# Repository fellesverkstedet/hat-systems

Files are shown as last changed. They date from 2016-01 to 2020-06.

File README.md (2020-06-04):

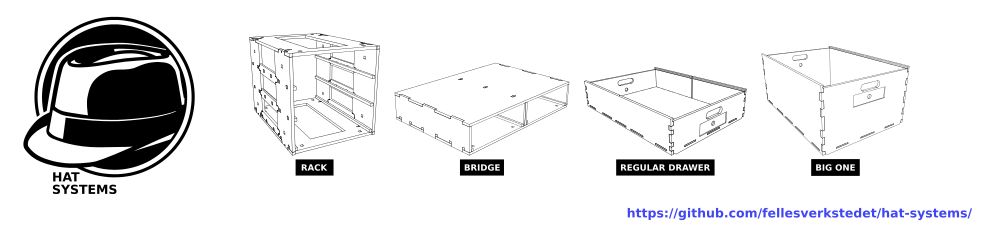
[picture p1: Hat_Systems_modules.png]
Modules overview


# Hat Systems
Hat Systems is a general purpose storage system for workshop storage of tools and inventory.

Designed with these basic principles in mind; modular, low-cost, heavy-duty/durable and spacious. The module sizes is designed to fit onto [EUR-palett](https://en.wikipedia.org/wiki/EUR-pallet), with a footprint size of 120x80 centimeter. This allows them to be moved around easily in an production or workshop environment, or even transported between locations.

Originally developed as for use in-house at [Fellesverkstedet](http://fellesverkstedet.no), now also in use at [Bitraf](http://bitraf.no), and open for reproduction across the world.

## License

Distributed under Creative Commons Attribution 4.0 International. [CC-BY 4.0](http://creativecommons.org/licenses/by/4.0/).

## Contributors
Conceptualized for Fellesverkstedet by [Hans Christian Skovholt](http://www.skovholt.net/) and Graham A. Hayward.

Modules have been produced by Jonas Sætervik, [Siemen Cuypupeiers](http://www.siemencuypers.com) and Anthony Poldervaart. And by Thomas Winther at Bitraf.

Have you made a Hat Systems module? Or have designed additional modules? [Let us know!](https://github.com/fellesverkstedet/hat-systems/issues/new).

## Example configurations

### Storage shelves

Per palett: `2x2 Rack`, with  `3x Drawer Regular` in most of the racks.

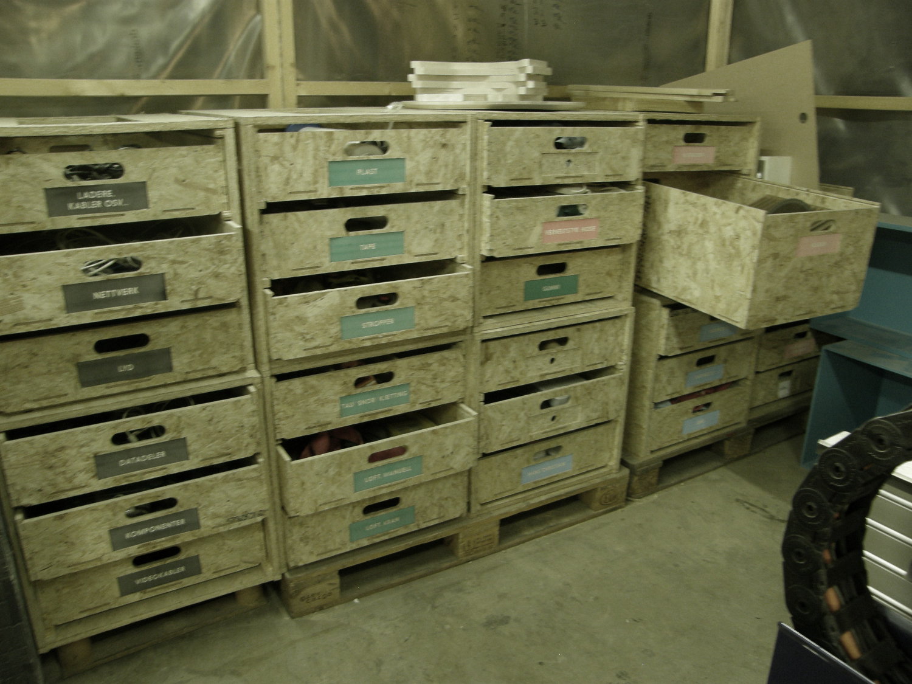
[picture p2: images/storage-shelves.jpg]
Storage shelves at Fellesverkstedet


### Laser material storage

`1x Material Storage` with `1x Bridge` on top.

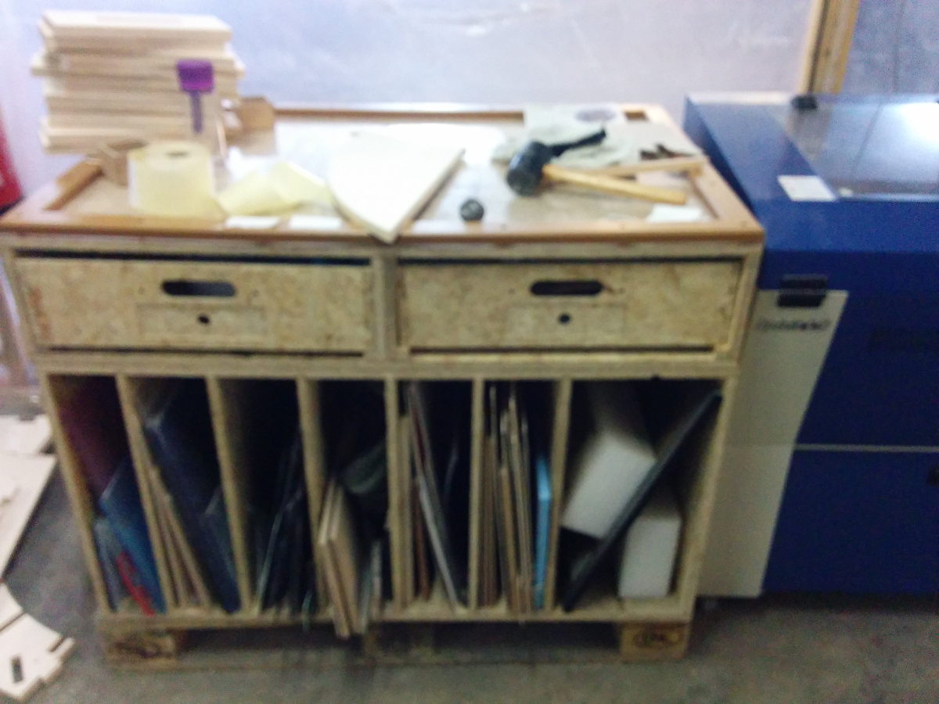
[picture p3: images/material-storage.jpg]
Material Storage for laser


## Roller table with drawers

`1x Rack` with `3x Drawer Regular`, a benchplate on top and wheels mounted underneath.
Very useful for moving large cutsheets and finished parts around workshop, to and from CNC router.

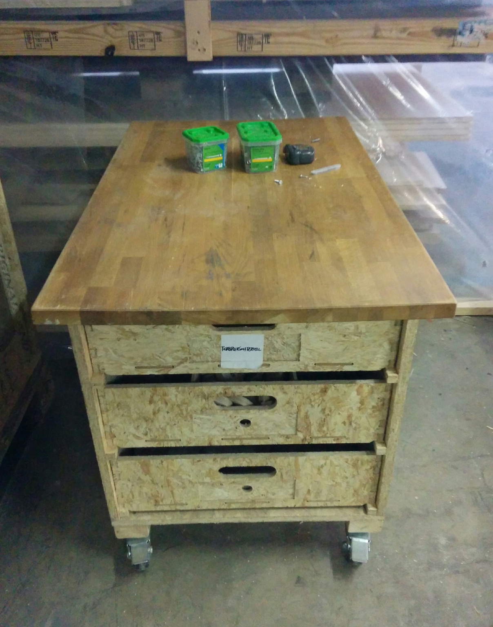
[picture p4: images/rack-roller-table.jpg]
Roller table with drawers


## Collaboration table

`2x Rack` with a tabletop made out of one old sacrificial layer from CNC and one white-painted sheet (120x240cm).
Comfortable to stand and work around, or one can sit on bar-style stools.

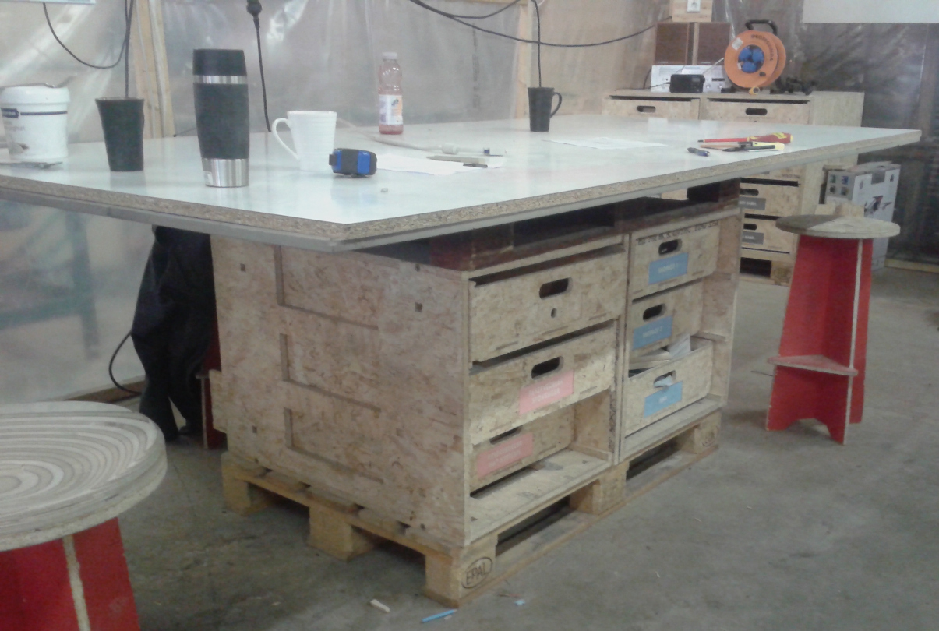
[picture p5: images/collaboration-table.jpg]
Big collaboration table


## Machine tools workbench

The machines on top of the work surface are each attached to a plate with chamfered edges.
An opposing chamfered edge in back, and  hinged profile in front locks the plates in place.
This allows some flexibility in moving the machines around.

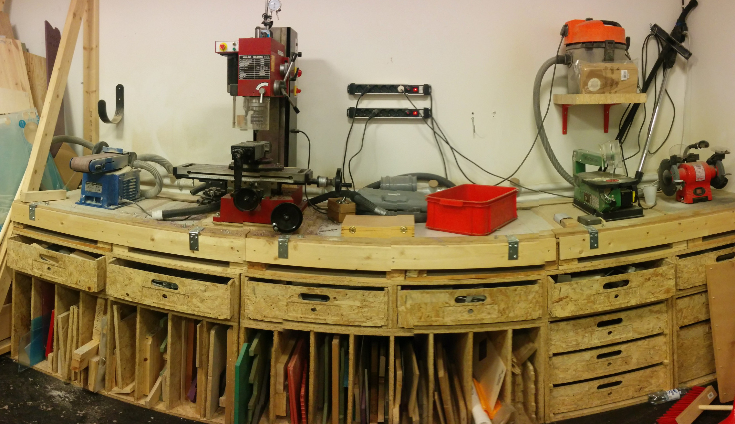
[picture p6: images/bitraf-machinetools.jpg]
Machine tools workbench

Picture from Bitraf makerspace.

## Prerequisites for making
You will need accesss to a large-scale CNC mill/router, capable of handling cutsheets of at least 60x80 cm (120x80 for current bridge design),
and cutting 18 mm [OSB](https://en.wikipedia.org/wiki/Oriented_strand_board).
Examples include the Shopbot PRS, or an extended Shapeoko/XCarve.

If you don't have access to such a machine, check out your local [FabLab](https://www.fablabs.io/map), makerspace or [hackerspace](https://wiki.hackerspaces.org/List_of_Hacker_Spaces)! Or find someone to manufacture it for you locally using [Fabhub.io directory](https://www.fabhub.io/directory).

Ready-to-use cutsheet geometry is included, but you will need to set up the toolpaths yourself using the CAM software for your machine.

## Modules

[Sketchup project source](./Hat_Systems_assembled.skp), for modifying or creating new modules.

### Rack

The base module, which drawers fit into.

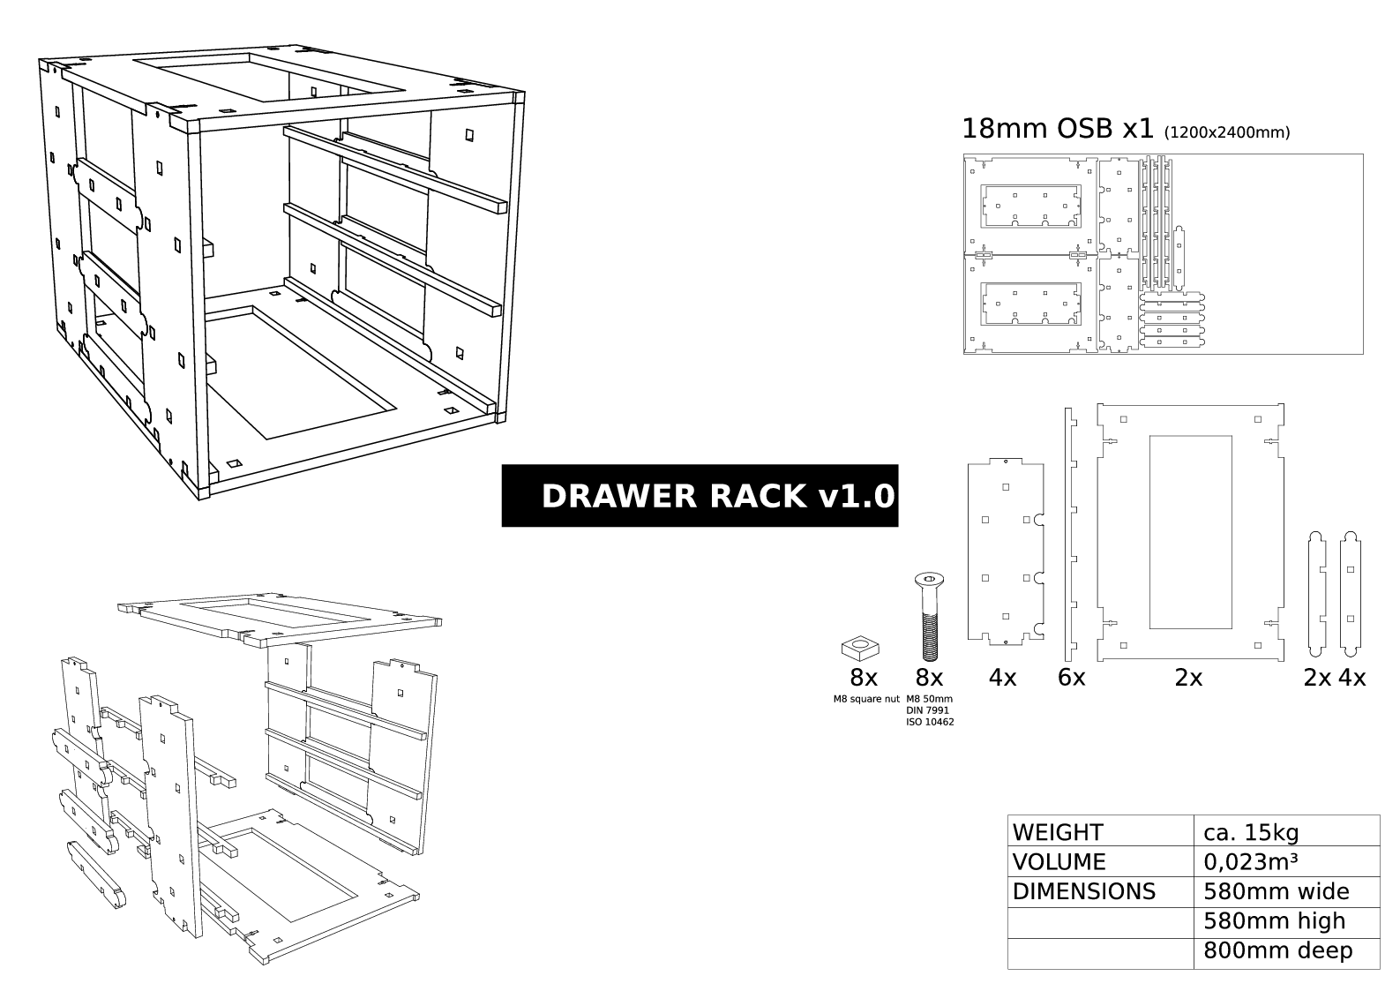
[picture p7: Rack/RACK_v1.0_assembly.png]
Rack assembly drawing


Made of 18mm OSB.

Is put together with 8 countersunk socket head M8 x 50mm bolts and square nuts M8 x 13 x 5MM (DIN 7991/ISO 10462).
The countersunk bolts facilitates placing two units side by side on a pallett.

The rack is assembled with bolts in order to make it possible to dissasemble for transport. But could theoretically be glued or screwed together as well.

[.DXF original geometry](./Rack/RACK_full_sheet_v1.0_no_dogbones_no_hdd.dxf) | 
[Cutsheet .DXF (includes dogboones & holddown, for <=6mm tool)](./Rack/RACK_full_sheet_v1.0_6mm_dogbones.dxf) | 
[.STL 3d-model](./Rack.stl)

### Drawer Regular

Regular drawer that will fit most stuff.

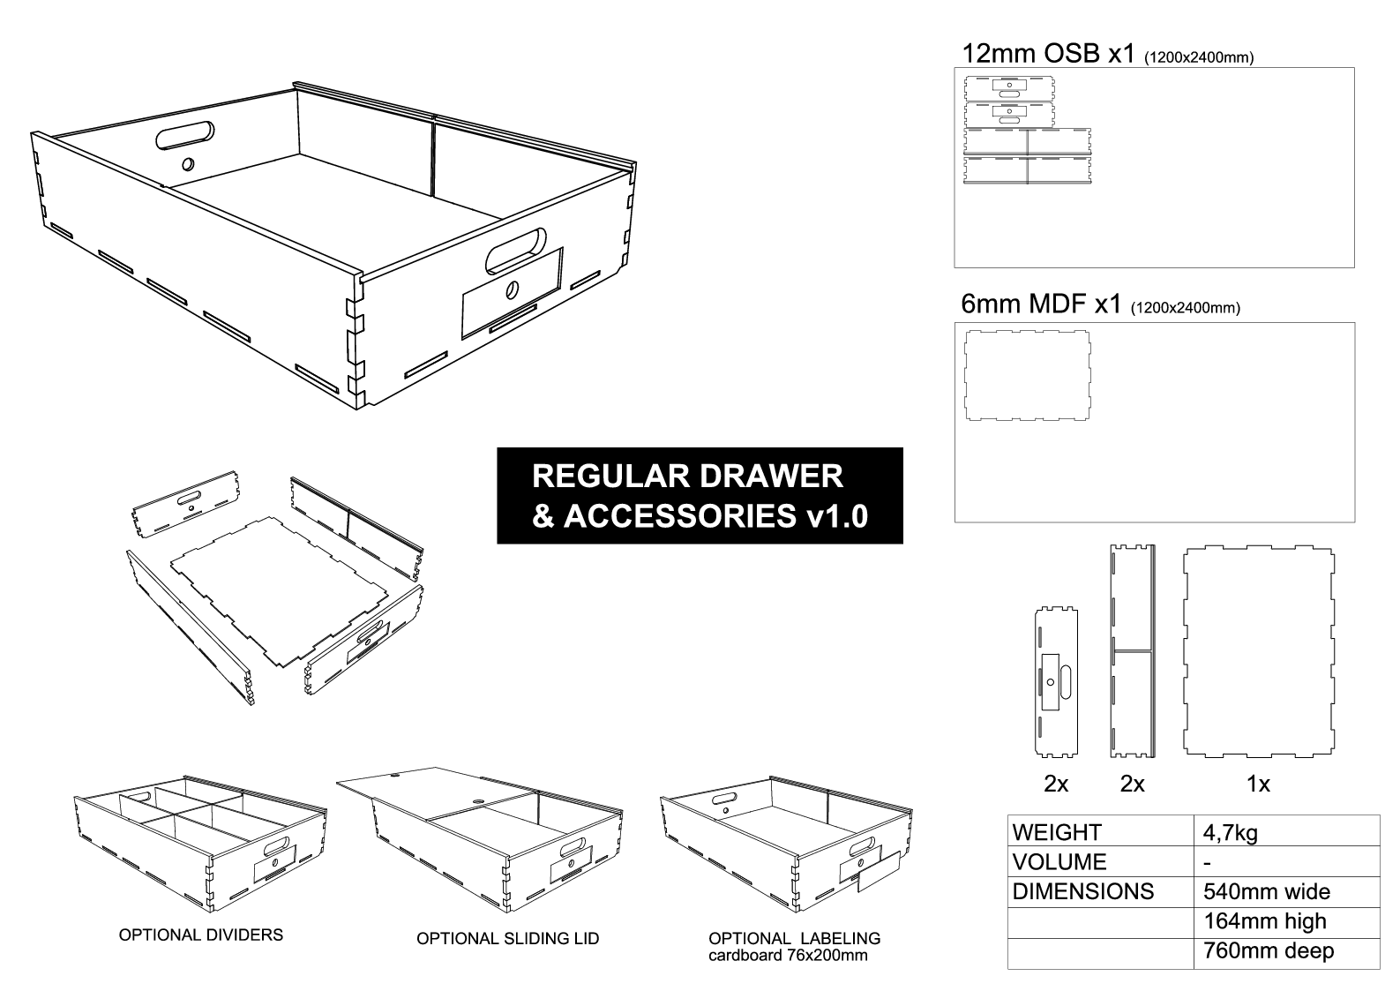
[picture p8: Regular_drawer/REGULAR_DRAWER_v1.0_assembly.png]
Drawer Regular assembly drawing


Made of 12mm OSB, as well as 6mm MDF for drawer bottoms.

[.DXF original geometry](./Regular_drawer/DRAWERS_REGULAR_full_sheet_v1.0_no_dogbones_no_hdd.dxf) | 
[Cutsheet .DXF (includes dogboones & holddown, for <=6mm tool)](./Regular_drawer/DRAWERS_REGULAR_full_sheet_v1.0_6mm_dogbones.dxf) | 
[.STL 3d-model](./Drawer_regular.stl)

You will also need one drawer bottom.

[.DXF original geometry](./Drawer_bottom/DRAWER_BOTTOM_full_sheet_v1.0_no_dogbones_no_hdd.dxf) | 
[Cutsheet .DXF (includes dogboones & holddown, for <=6mm tool)](./Drawer_bottom/DRAWER_BOTTOM_full_sheet_v1.0_6mm_dogbones.dxf) | 

### Drawer BigOne

Supersized drawer, takes the place of two regular drawers in height. Otherwise identical to Drawer Regular.

[.DXF original geometry](./Big_One_drawer/BIG_ONE_Drawer_no_dogbones.dxf) | 
[Cutsheet .DXF (includes dogboones & holddown, for <=6mm tool)](./Big_One_drawer/BIG_ONE_Drawer_6mm_dogbones.dxf) | 
[.STL 3d-model](./Drawer_big_one.stl)

You will also need one drawer bottom, see above!

### Bridge

Forms a solid surface on top of two racks, as well as housing for two regular drawers.
Useful to create a working sturface, with height comfortable for standing work.

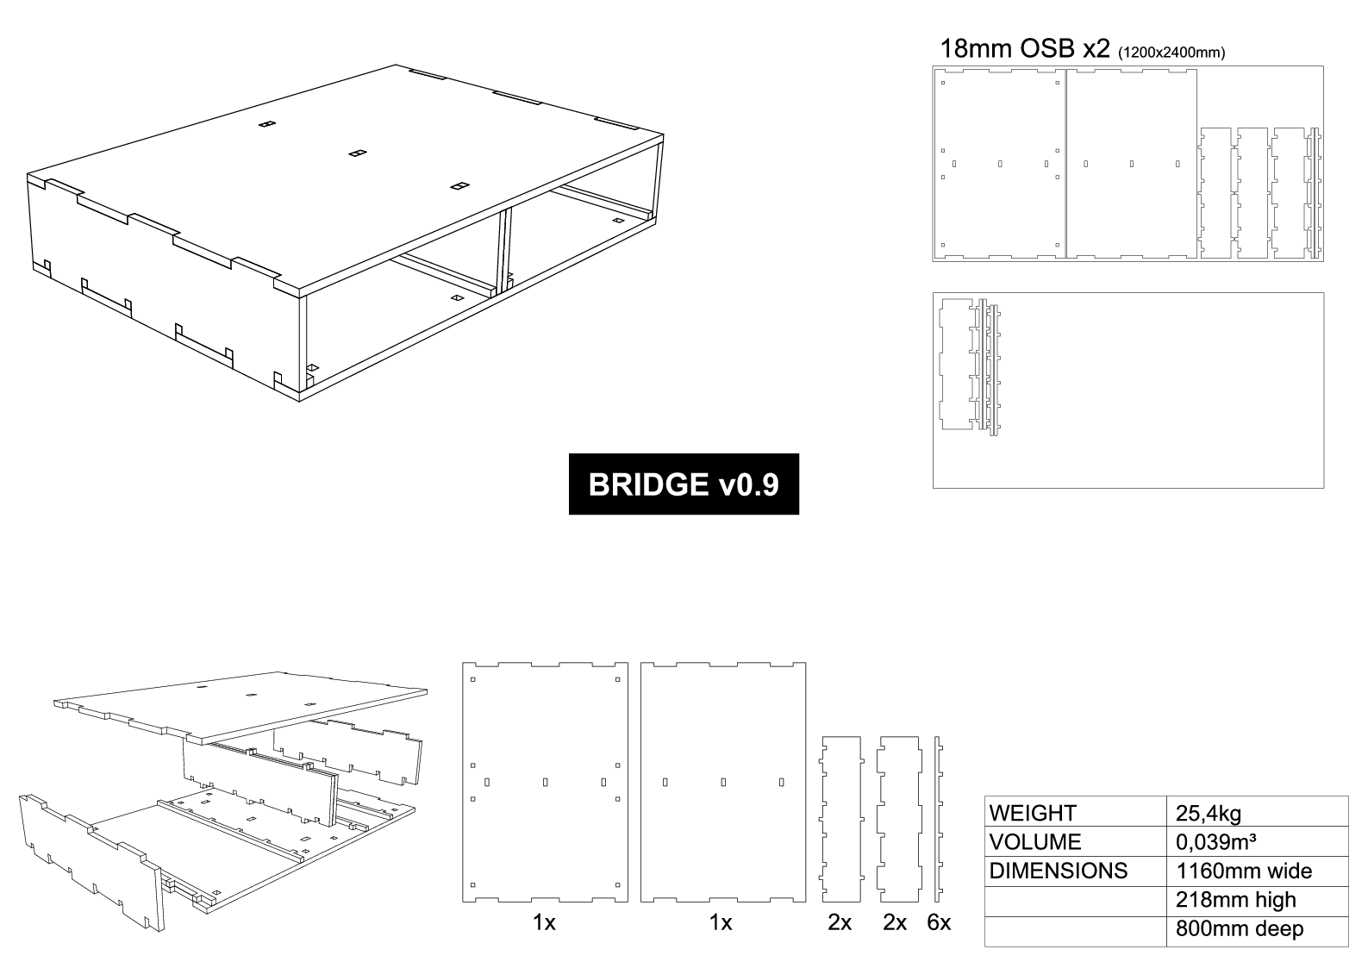
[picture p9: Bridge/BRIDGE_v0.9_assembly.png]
Bridge assembly drawing


Original geometry [.DXF 1](./Big_One_drawer/Bridge/BRIDGE_v0.9_no_dogbones_1of2.dxf) [.DXF 2](./Big_One_drawer/Bridge/BRIDGE_v0.9_no_dogbones_2of2.dxf) | 

## Material Storage

Full-width module for storing materials vertically.

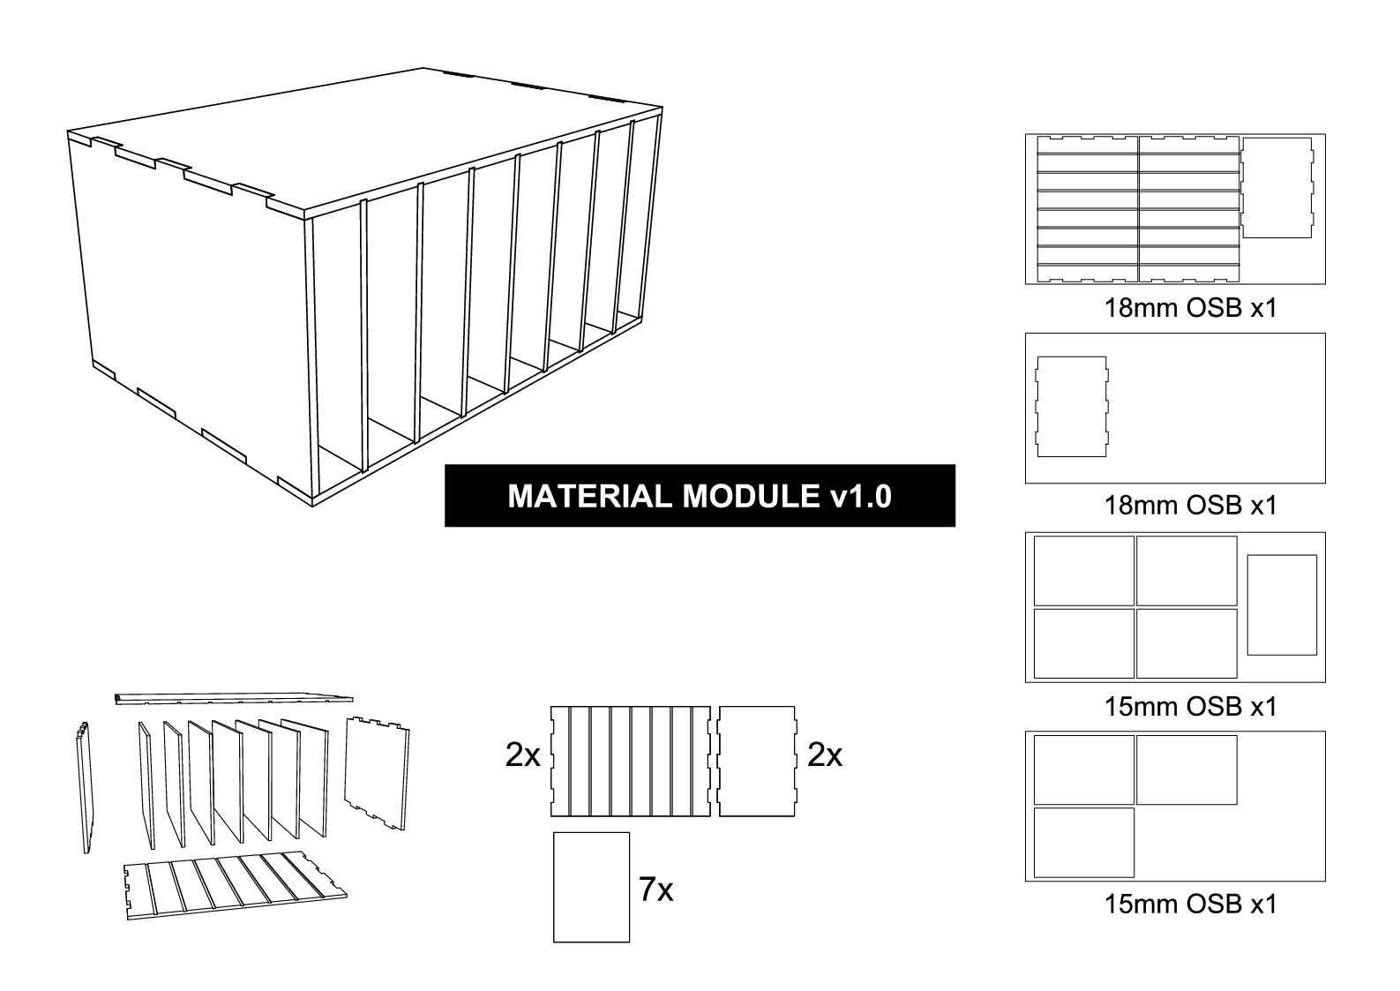
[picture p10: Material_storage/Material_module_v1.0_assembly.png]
Material storage assembly drawing


**Work-in-progress!** Files should be scrutinized before any attempt to produce.

[Sketchup project](./Material_storage/Material_storage.skp) | 
[.DXF export](./Material_storage/Material_storage.dxf) | 
[.STL 3d-model](./Material_storage/Material_storage.stl)

## Trash cans

**Work-in-progress!** Files currently missing.

Trash can rack, including 3x trash cans.

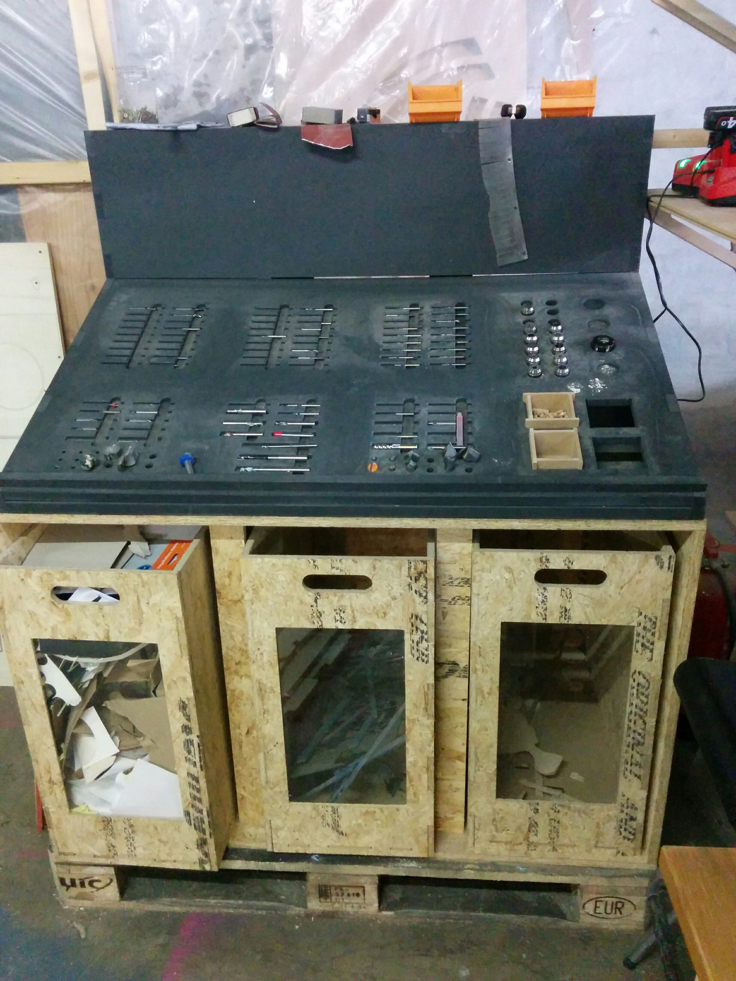
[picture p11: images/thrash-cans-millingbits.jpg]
Trash cans module


The ER20 collet and milling bit holder on top is also to-be-released.

### Design iterations in the wild
* A [bedbunk drawer](https://github.com/apetrynet/bunk_drawers) variation by apetrynet, designed in Freecad

## TODO

* Add picture of Bitraf island module, and design files
* Material Storage: Finish/verify files, mark complete.
* Rack: Remove mostly-unused bolt holes in sides. They stay still by their own weight.
* Add a template .SVG file for drawer label (for ease of making on laser/printer)
* Trash cans: Publish files, create assembly drawing
* Milling bit holder: Publish in separate project, link here

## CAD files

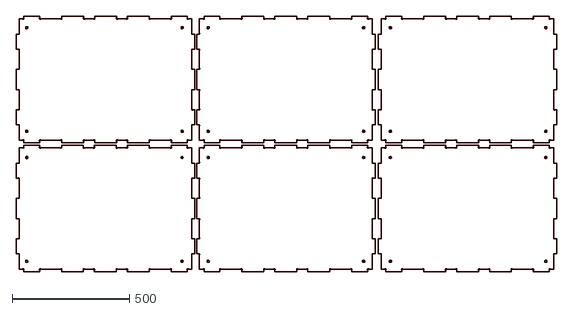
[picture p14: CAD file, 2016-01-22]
Drawer_bottom/DRAWER_BOTTOM_full_sheet_v1.0_6mm_dogbones.dxf
2301.5 x 1089.0

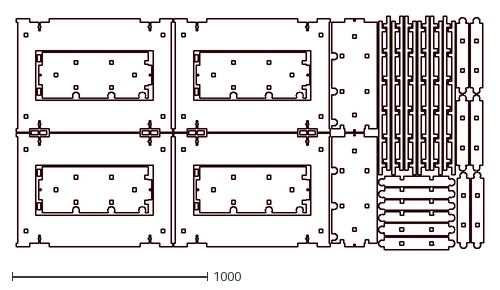
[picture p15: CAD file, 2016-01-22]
Rack/RACK_full_sheet_v1.0_no_dogbones_no_hdd.dxf
2390.7 x 1194.8

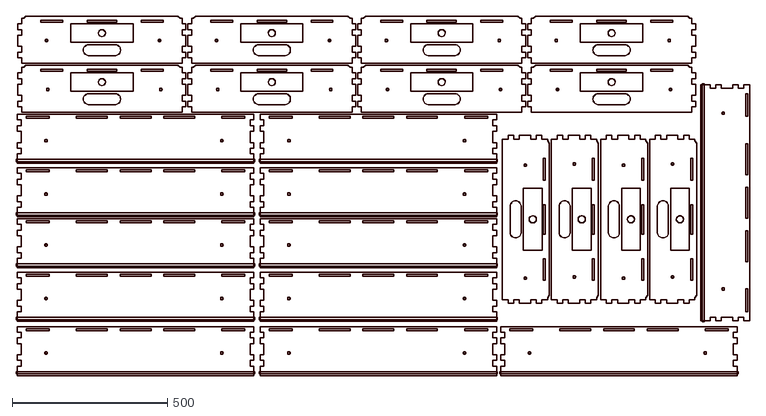
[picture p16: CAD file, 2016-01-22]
Regular_drawer/DRAWERS_REGULAR_full_sheet_v1.0_no_dogbones.dxf
2357.3 x 1155.5

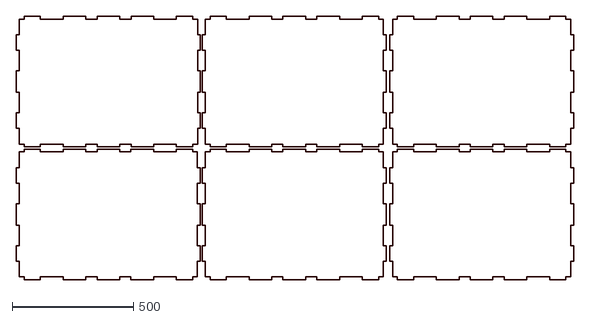
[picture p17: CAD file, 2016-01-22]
Drawer_bottom/DRAWER_BOTTOM_full_sheet_v1.0_no_dogbones_no_hdd.dxf
2301.5 x 1089.0

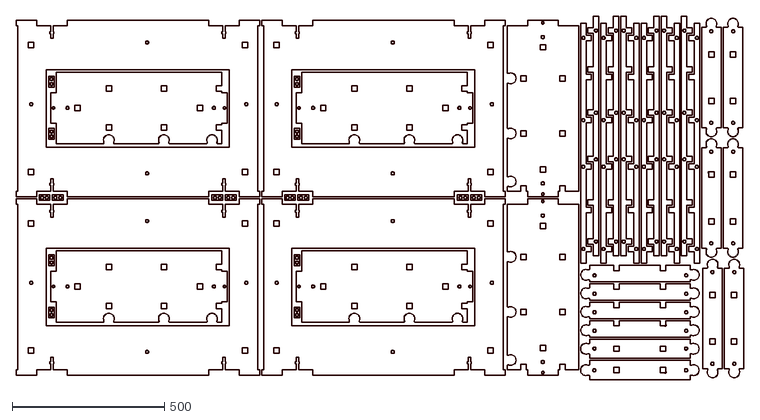
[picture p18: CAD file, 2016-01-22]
Rack/RACK_full_sheet_v1.0_no_dogbones.dxf
2390.7 x 1194.8

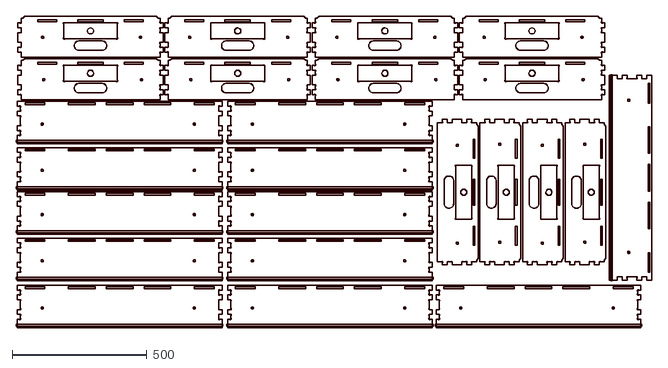
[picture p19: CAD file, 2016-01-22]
Regular_drawer/DRAWERS_REGULAR_full_sheet_v1.0_6mm_dogbones.dxf
2357.3 x 1155.5

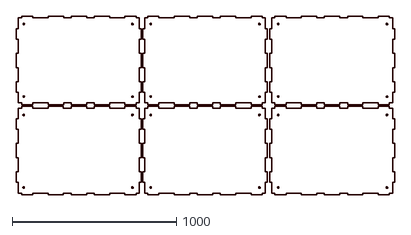
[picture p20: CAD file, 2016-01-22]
Drawer_bottom/DRAWER_BOTTOM_full_sheet_v1.0_no_dogbones.dxf
2301.5 x 1089.0

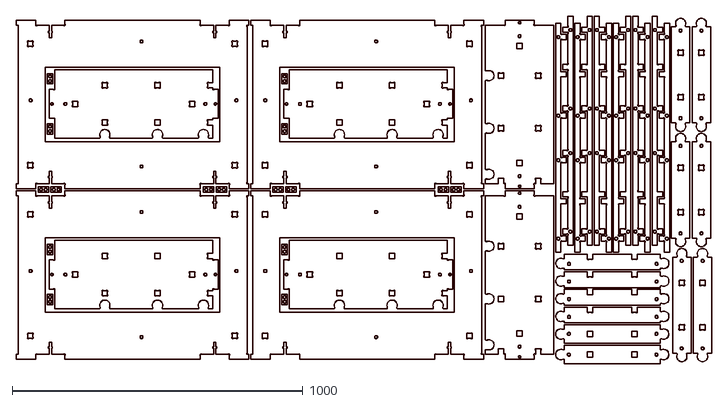
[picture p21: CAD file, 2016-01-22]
Rack/RACK_full_sheet_v1.0_6mm_dogbones.dxf
2390.7 x 1194.8

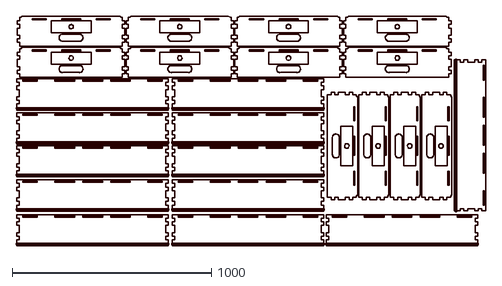
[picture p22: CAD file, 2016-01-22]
Regular_drawer/DRAWERS_REGULAR_full_sheet_v1.0_no_dogbones_no_hdd.dxf
2357.3 x 1155.5

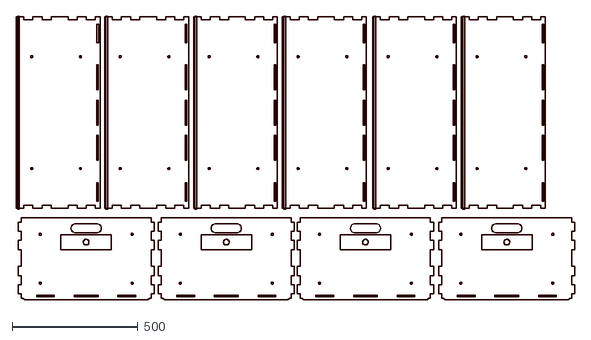
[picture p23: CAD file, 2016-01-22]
Big_One_drawer/BIG_ONE_Drawer_no_dogbones.dxf
2217.9 x 1126.4

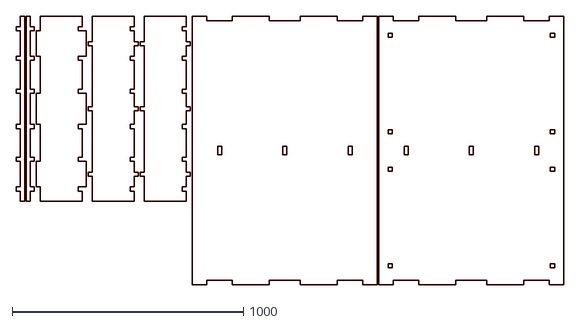
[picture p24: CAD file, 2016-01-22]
Bridge/BRIDGE_v0.9_no_dogbones_1of2.dxf
2369.5 x 1160.0

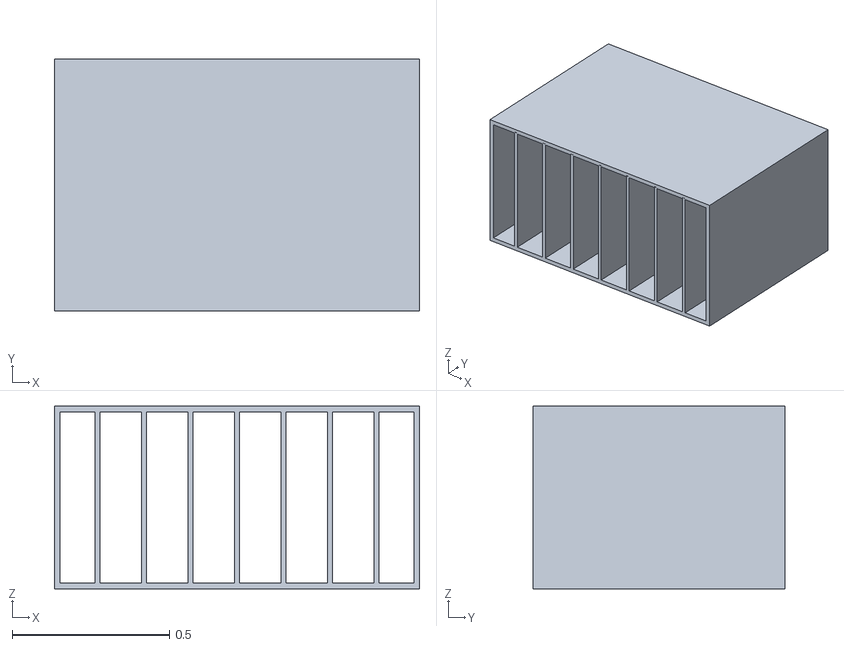
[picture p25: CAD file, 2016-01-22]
Material_storage/Material_storage.stl
1.16 x 0.8 x 0.58

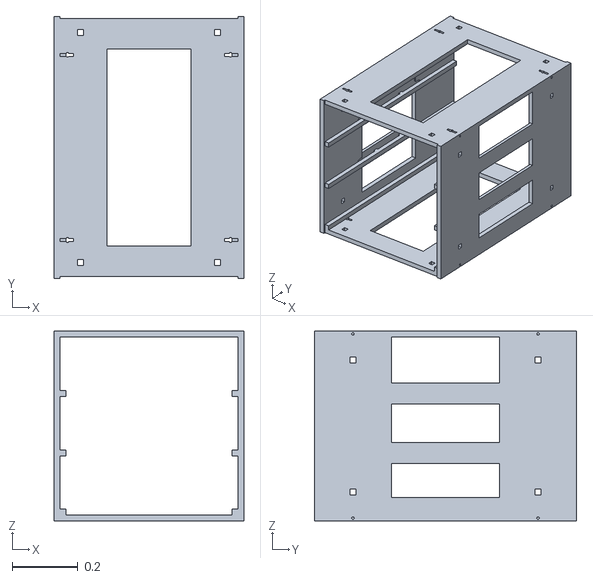
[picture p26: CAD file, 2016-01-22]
Rack.stl
0.58 x 0.8 x 0.58

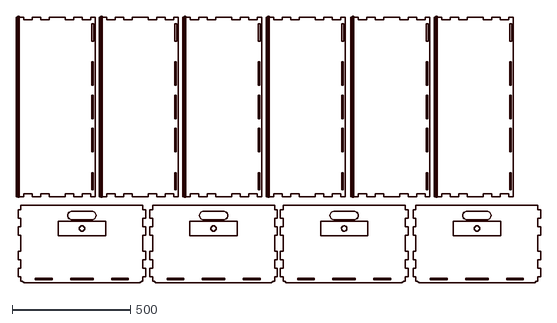
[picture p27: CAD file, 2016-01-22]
Big_One_drawer/BIG_ONE_Drawer_no_dogbones_no_hdd.dxf
2217.9 x 1126.4

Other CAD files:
Bridge/BRIDGE_v0.9_no_dogbones_sheet_2of2.dxf
Drawer_big_one.stl
Big_One_drawer/BIG_ONE_Drawer_6mm_dogbones.dxf
Drawer_regular.stl
Hat_Systems_assembled.skp
Material_storage/Material_storage.dxf
Material_storage/Material_storage.skp

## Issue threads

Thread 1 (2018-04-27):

Avoiding loose pieces

Jaknil, 2018-04-27:
If the parts for the rack are CAMed with only hold-down and profile and cut with an up-cut bit, then there is a large chance that there will be loose pieces popping out of the cut sheet potentially jamming the machine or worse. I suggest that some hold down holes are added to the long sides and that the small pieces are removed with a pocket operation, some profiles need to be added for this.

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

Note: This happened, the X-axis stalled, causing the bit to hit a screw, get damaged and go wild in the sheet leaving burn marks before the machine was stopped. We switched to a compression bit which left the floating pieces in the sheet.

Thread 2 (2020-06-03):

Hat-System variation, paying my dues :)

apetrynet, 2020-06-03:
Hey!

I just wanted to let you know that I'm creating a [variation](https://github.com/apetrynet/bunk_drawers) of the Hat-System for storage under my summer cabin bunk bed.

Thanks for this awesome design!

JensDyvik, 2020-06-04:
Super awesome to see Daniel. Thank your for sharing the link! And great to see you are working with freecad. I have grown very fund of working with freecad lately. Especially using the a spreadsheet with aliases as a parametric design interface/driver

Closed 2020-06-04.

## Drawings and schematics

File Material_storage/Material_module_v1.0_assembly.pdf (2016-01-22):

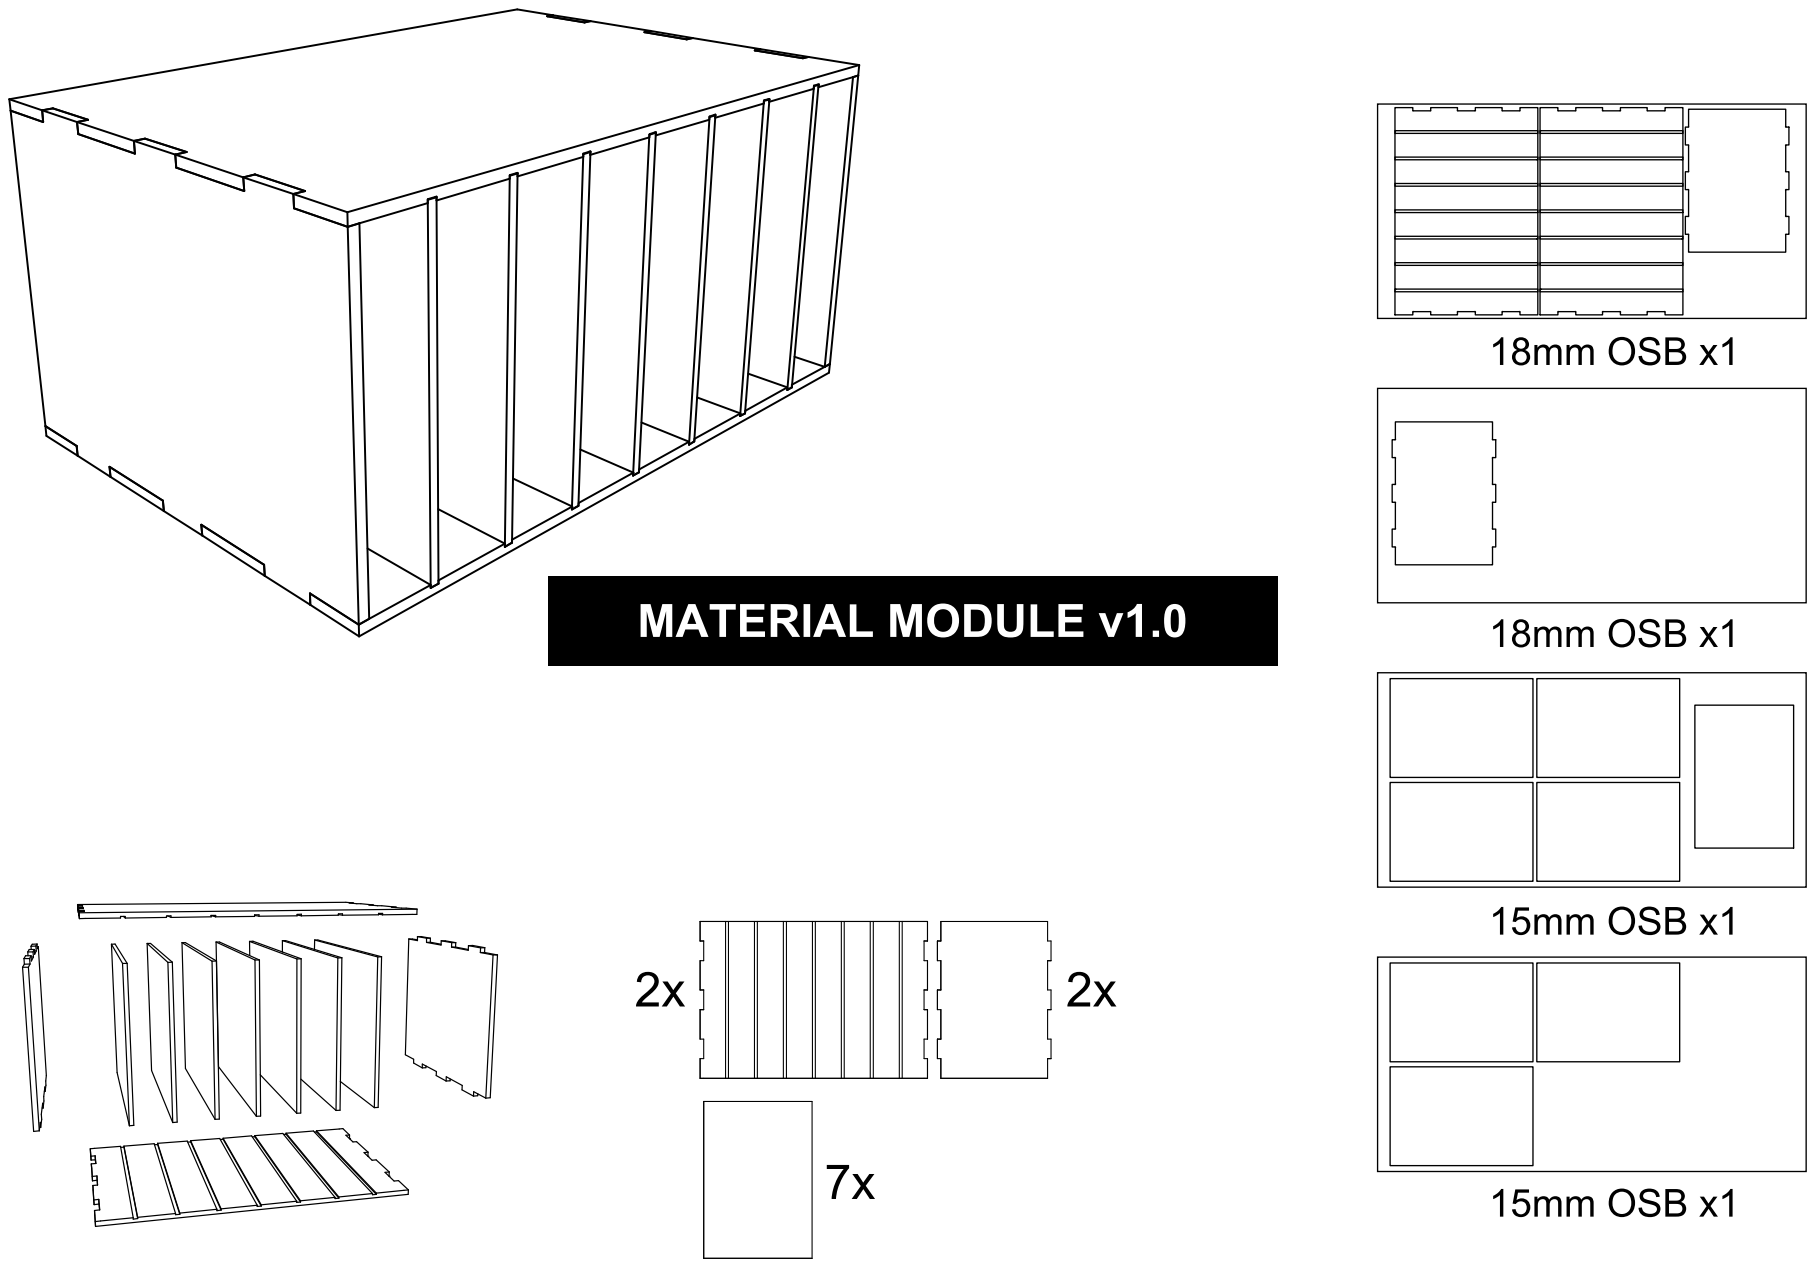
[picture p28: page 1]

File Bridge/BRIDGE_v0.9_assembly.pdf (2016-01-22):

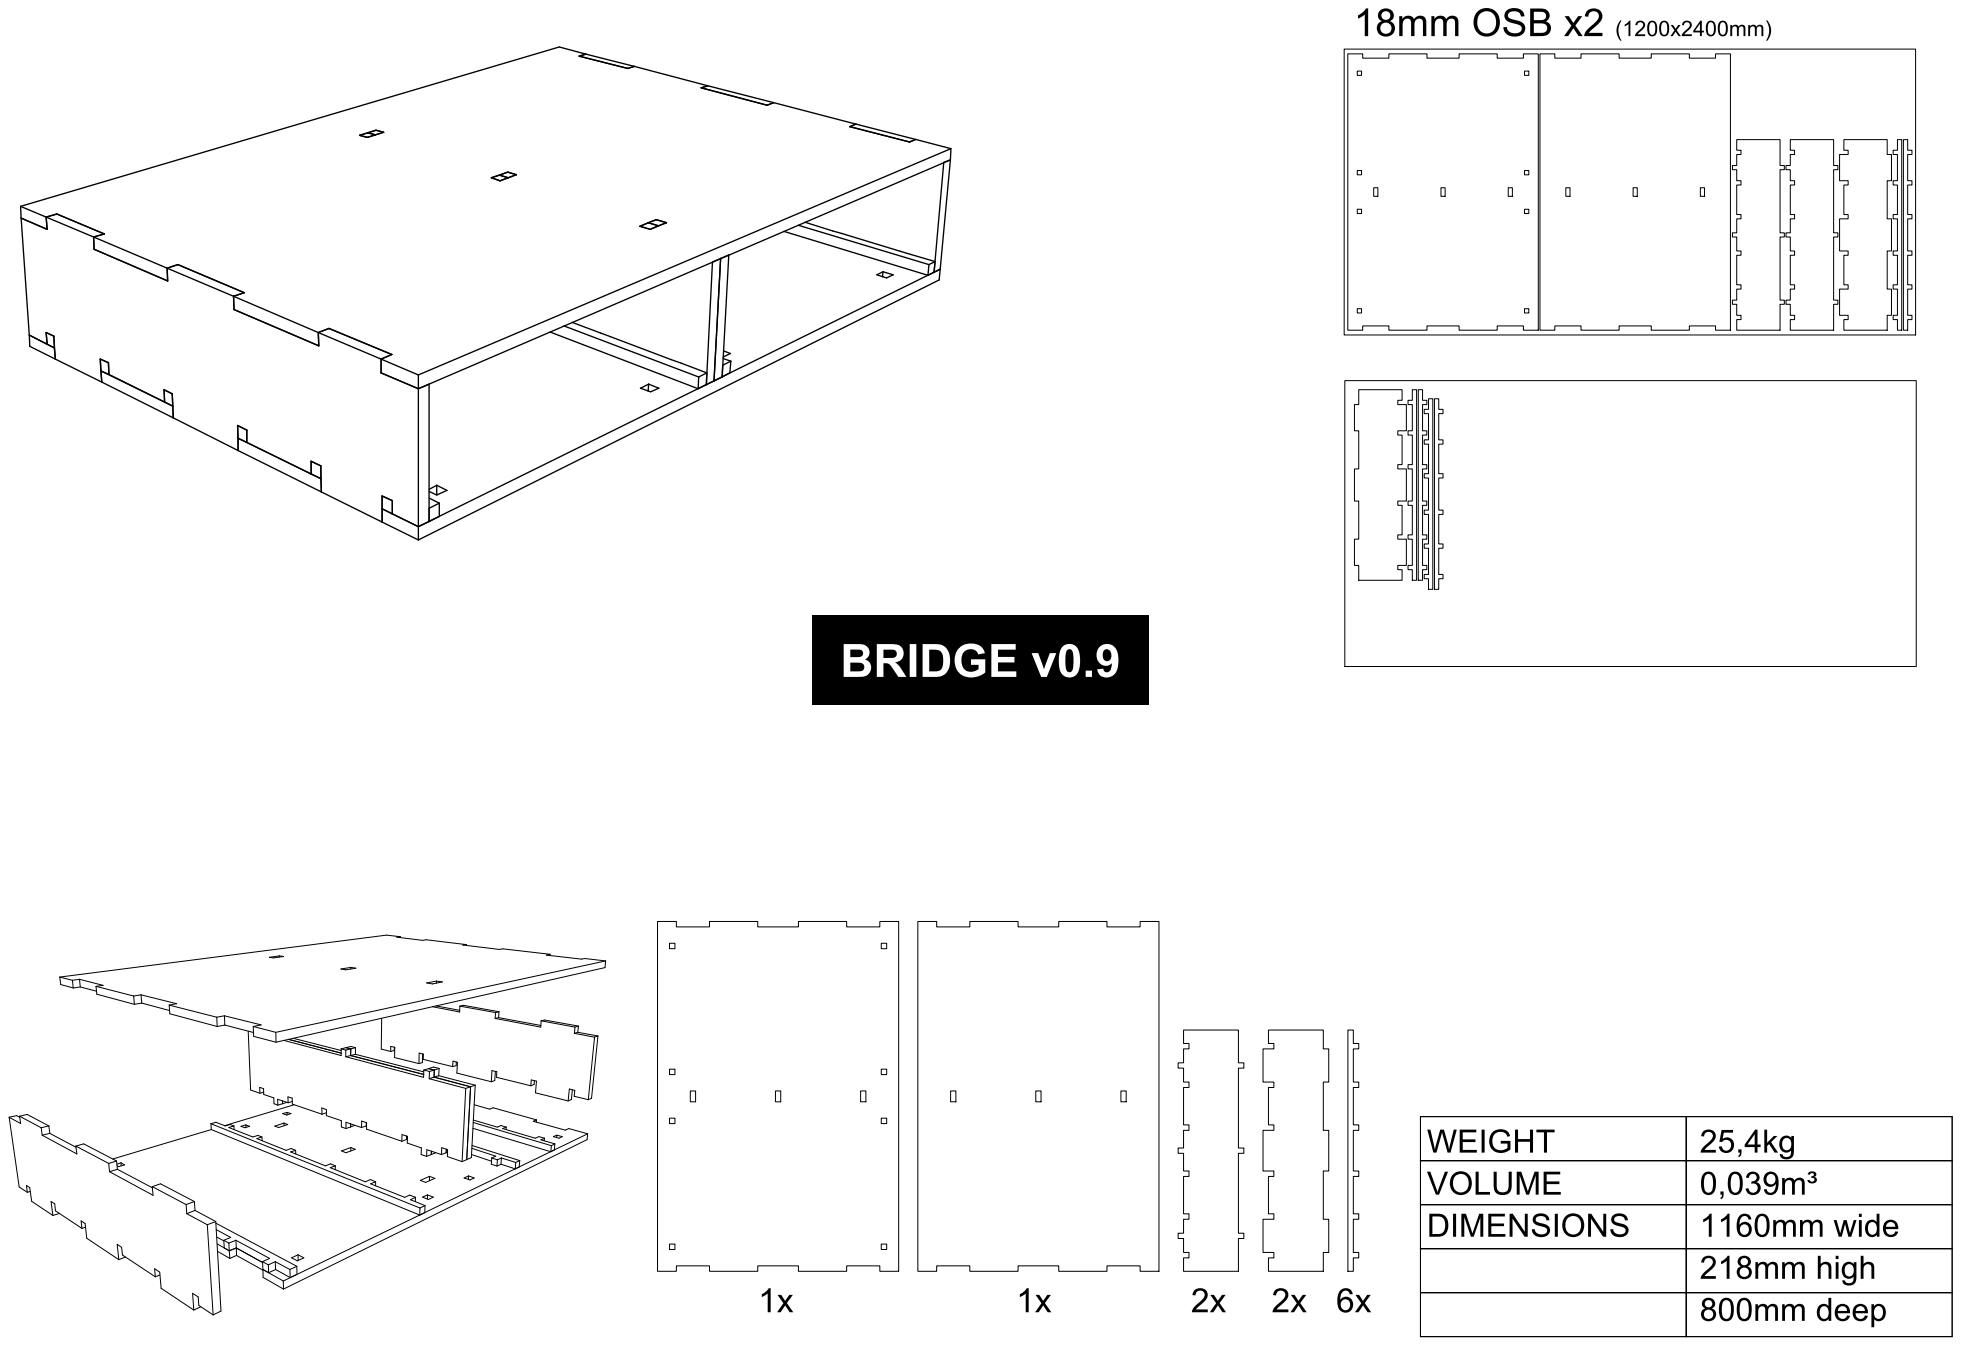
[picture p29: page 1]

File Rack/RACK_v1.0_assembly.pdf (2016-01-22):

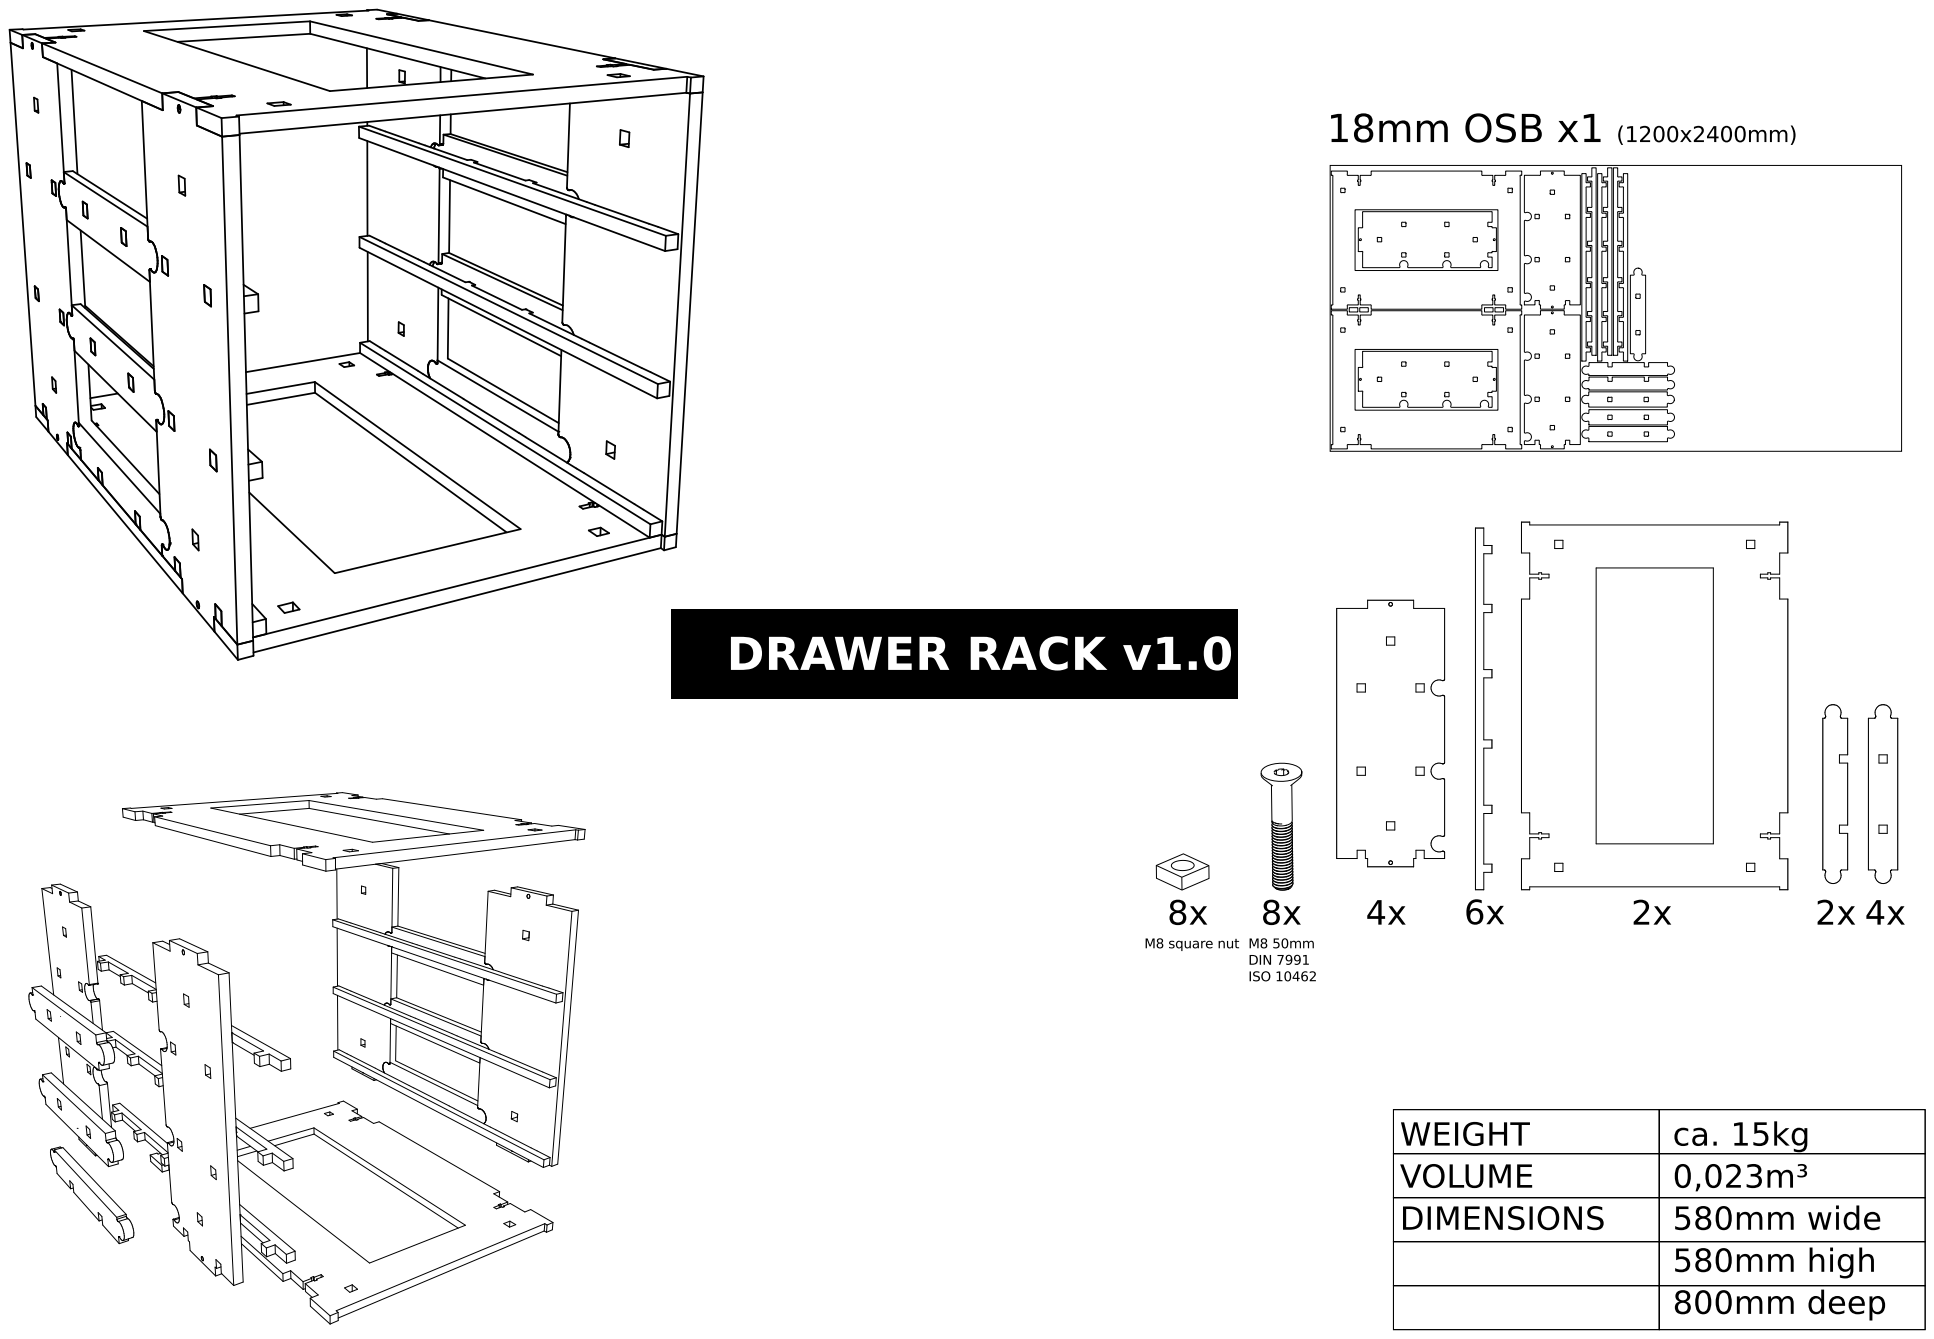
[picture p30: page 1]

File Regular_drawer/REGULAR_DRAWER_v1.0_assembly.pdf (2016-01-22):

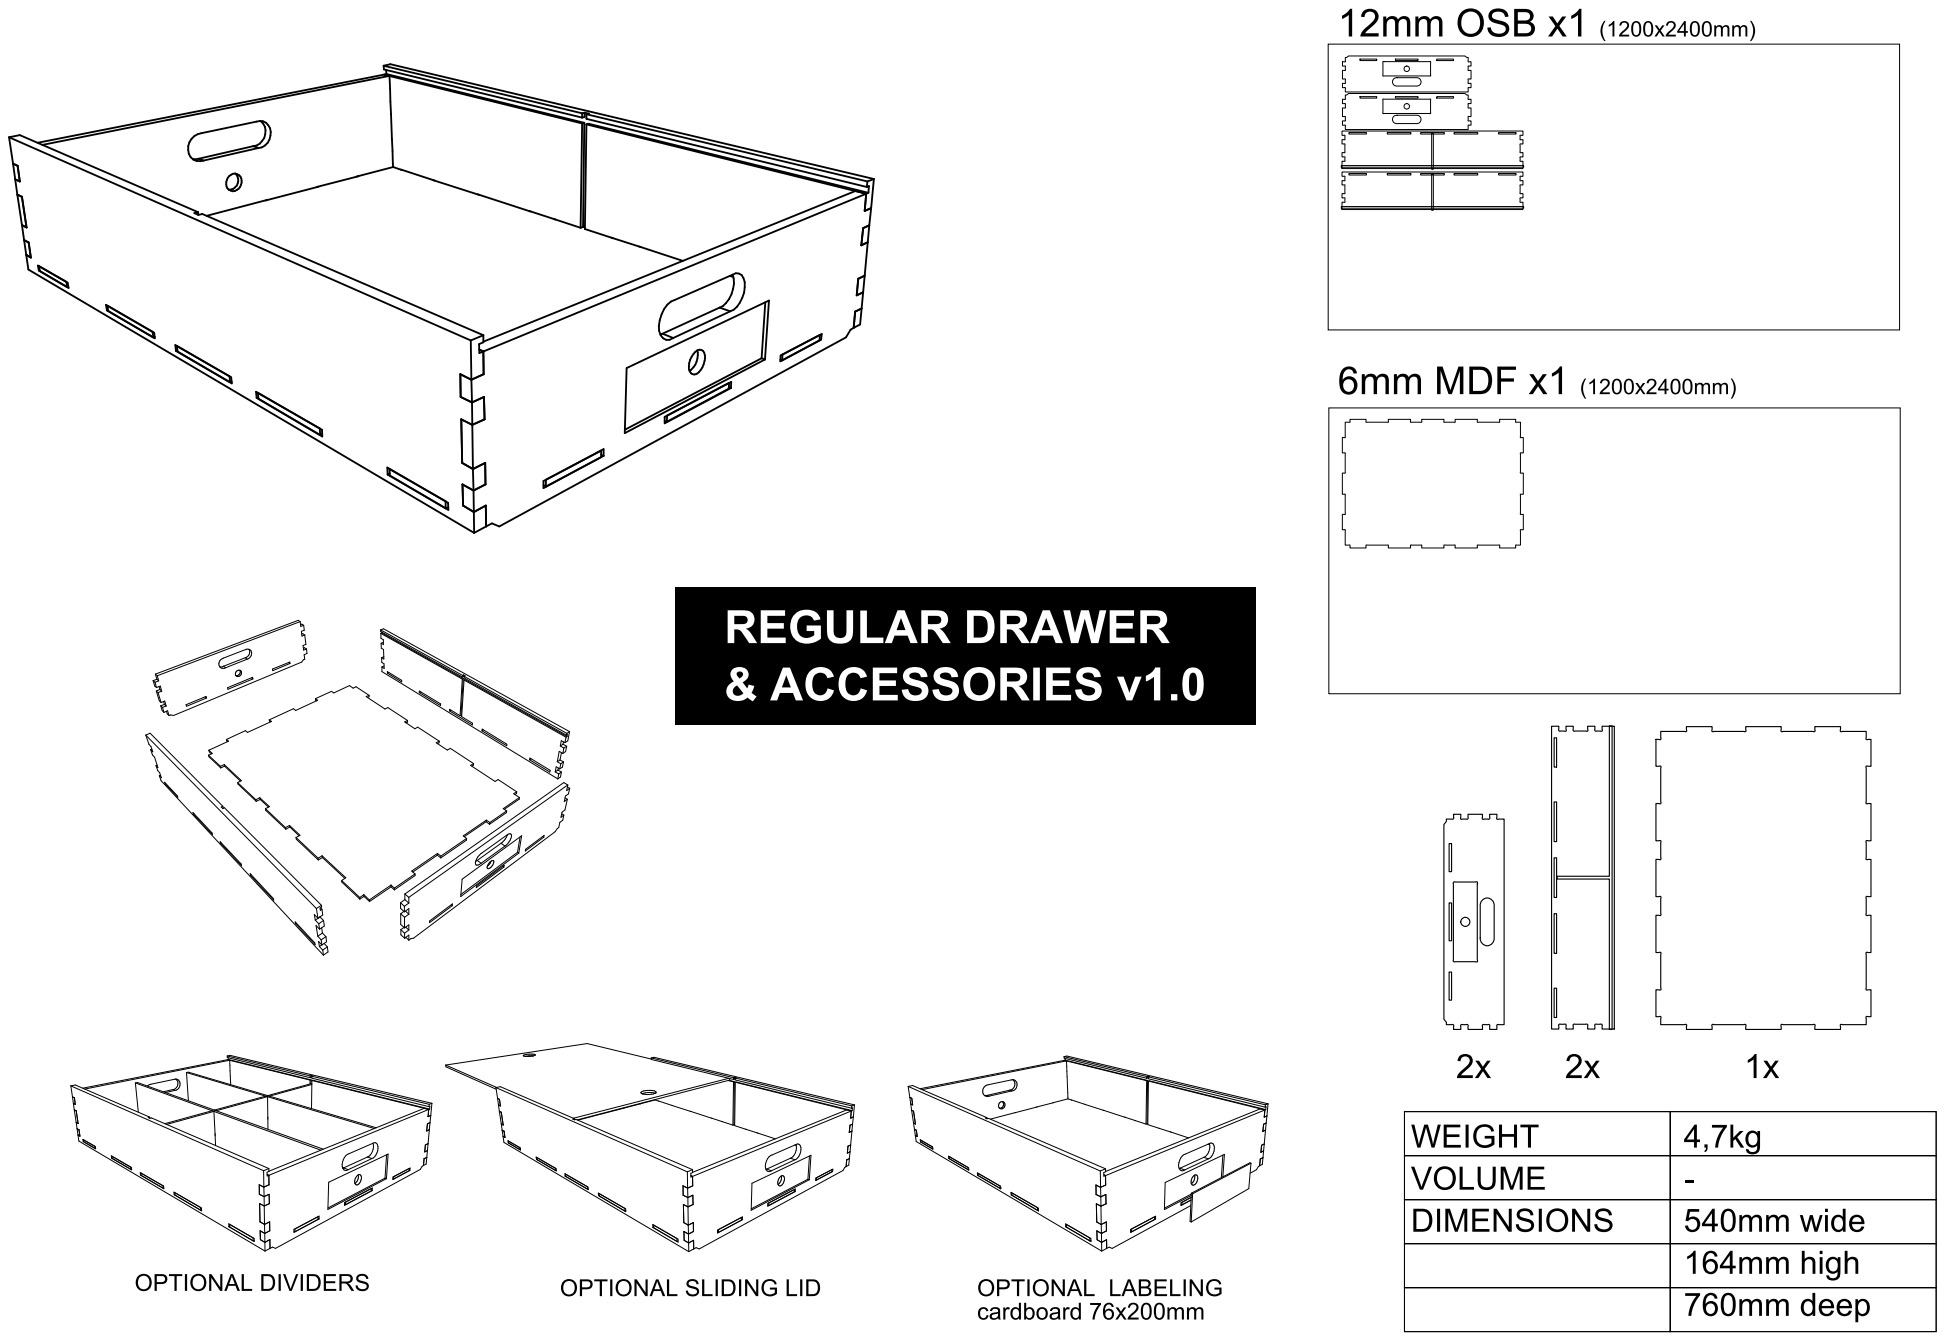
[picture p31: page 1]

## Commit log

2016-01-22 Delete BIG_ONE_Drawer_6mm_dogbones.dxf
    cleanup
    [BIG_ONE_Drawer_6mm_dogbones.dxf]
2016-01-22 Delete BIG_ONE_Drawer_no_dogbones.dxf
    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
    [BIG_ONE_Drawer_no_dogbones.dxf]
2016-01-22 Delete BIG_ONE_Drawer_no_dogbones_no_hdd.dxf
    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
    [BIG_ONE_Drawer_no_dogbones_no_hdd.dxf]
2016-01-22 Delete BRIDGE_v0.9_no_dogbones_1of2.dxf
    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
    [BRIDGE_v0.9_no_dogbones_1of2.dxf]
2016-01-22 Delete BRIDGE_v0.9_no_dogbones_sheet_2of2.dxf
    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
    [BRIDGE_v0.9_no_dogbones_sheet_2of2.dxf]
2016-01-22 Delete DRAWERS_REGULAR_full_sheet_v1.0_6mm_dogbones.dxf
    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
    [DRAWERS_REGULAR_full_sheet_v1.0_6mm_dogbones.dxf]
2016-01-22 Delete DRAWERS_REGULAR_full_sheet_v1.0_no_dogbones.dxf
    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
    [DRAWERS_REGULAR_full_sheet_v1.0_no_dogbones.dxf]
2016-01-22 Delete DRAWERS_REGULAR_full_sheet_v1.0_no_dogbones_no_hdd.dxf
    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
    [DRAWERS_REGULAR_full_sheet_v1.0_no_dogbones_no_hdd.dxf]
2016-01-22 Move assembly drawing into module directories
2016-01-22 Remove duplicate files, now inside Rack/ and Drawer_bottom/
    [DRAWER_BOTTOM_full_sheet_v1.0_6mm_dogbones.dxf, DRAWER_BOTTOM_full_sheet_v1.0_no_dogbones.dxf, DRAWER_BOTTOM_full_sheet_v1.0_no_dogbones_no_hdd.dxf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]
2016-01-22 Add rendered PNGs of assembly PDFs
    Generated using
    ./scripts/assembly-pngs.sh
2016-01-22 README: Add assembly drawing images
2016-01-22 Rename assembly images to .png
    Looks like Github Pages does not show .pdf.png as images
2016-01-22 README: Mention that bridge needs 120 cm CNC
2016-01-22 material storage module
    [Material_storage.dxf, Material_storage.skp]
2016-01-23 README: Add Material Storage picture, links to files
2016-01-23 README: Add images of laser storage and WIP trash cans
2016-01-23 README: Fix image of material storage assembly
